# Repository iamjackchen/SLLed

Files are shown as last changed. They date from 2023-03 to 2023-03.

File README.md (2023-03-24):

# SLLed

A decorative lighting piece I designed and built for Valentine's day. The project is called "SLLed" because the intended recipient had supposedly caught me talking about singly-linked lists in my sleep.

Inspired by https://www.instructables.com/DIY-LED-heart/. 

</br>

## Hardware

I first started by building a schematic in KiCAD. Some design considerations:

 - I was at uni and didn't have access to my usual soldering equipment, so I had to get my PCB assembled by its manufacturer. This meant that my component selection was restricted to what the manufacturer had available. 

 - I also didn't have access to any mcu programming tools, so I wanted this module to be USB-programmable for ease of development. USB-C because, c'mon guys, it's 2023.

For the MCU I settled for the ATMega16U2, which is from the family of microcontrollers used in the classic Arduino line (the commonly-used 32U4 was out of stock). 

I added a 16MHZ crystal should I choose to implement some form of USB connectivity with a host device in the future (for which the 16U2's internal crystal would be insufficient).

I also designed a very simple MOSFET-based power-switching circuit so that this module can be powered both via battery and USB.
 
The final schematic may be found [here](https://github.com/iamjackchen/SLLed/blob/master/Hardware/schematic.pdf).

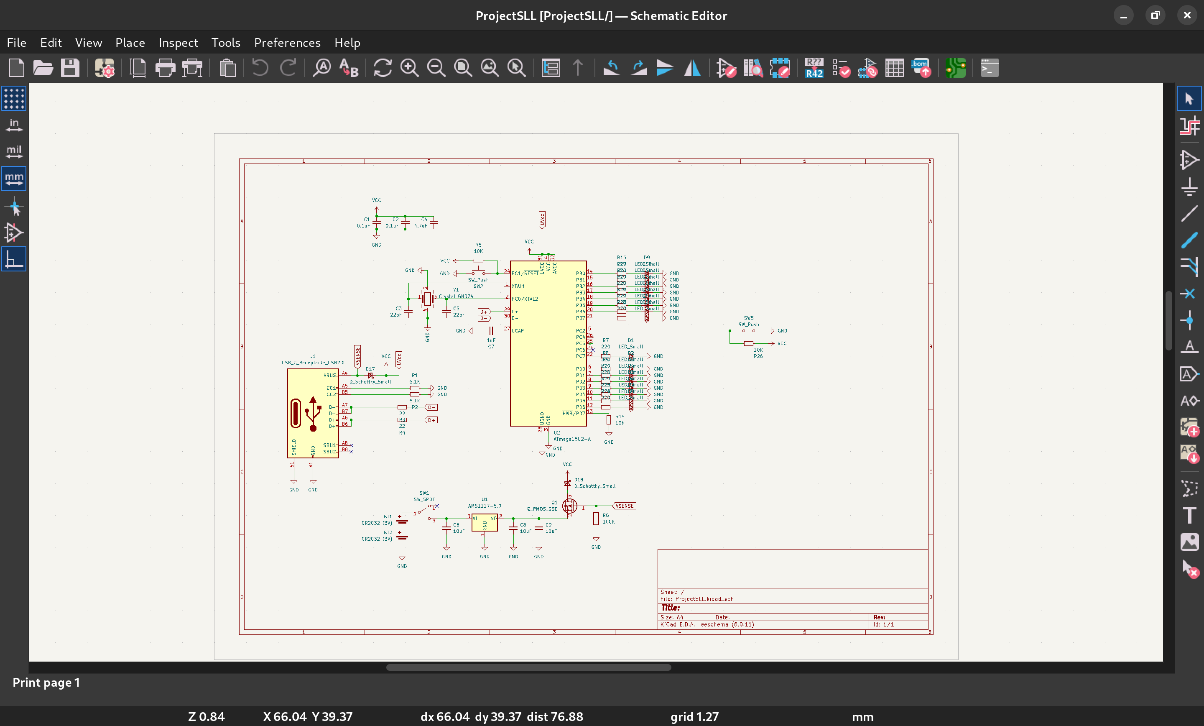
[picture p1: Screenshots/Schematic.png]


<br/>

I then assigned footprints to components and build a quick layout. Some design considerations:

 - For reasons of aesthetic purity, everything visible on the front-side of the PCB must be part of the heart. No vias outside of the heart!

 - Added a small hole to the top of the PCB, so you could thread a string through it and hang the module on somewhere

The geometry of the heart took some time to get right, but it turned out ok.

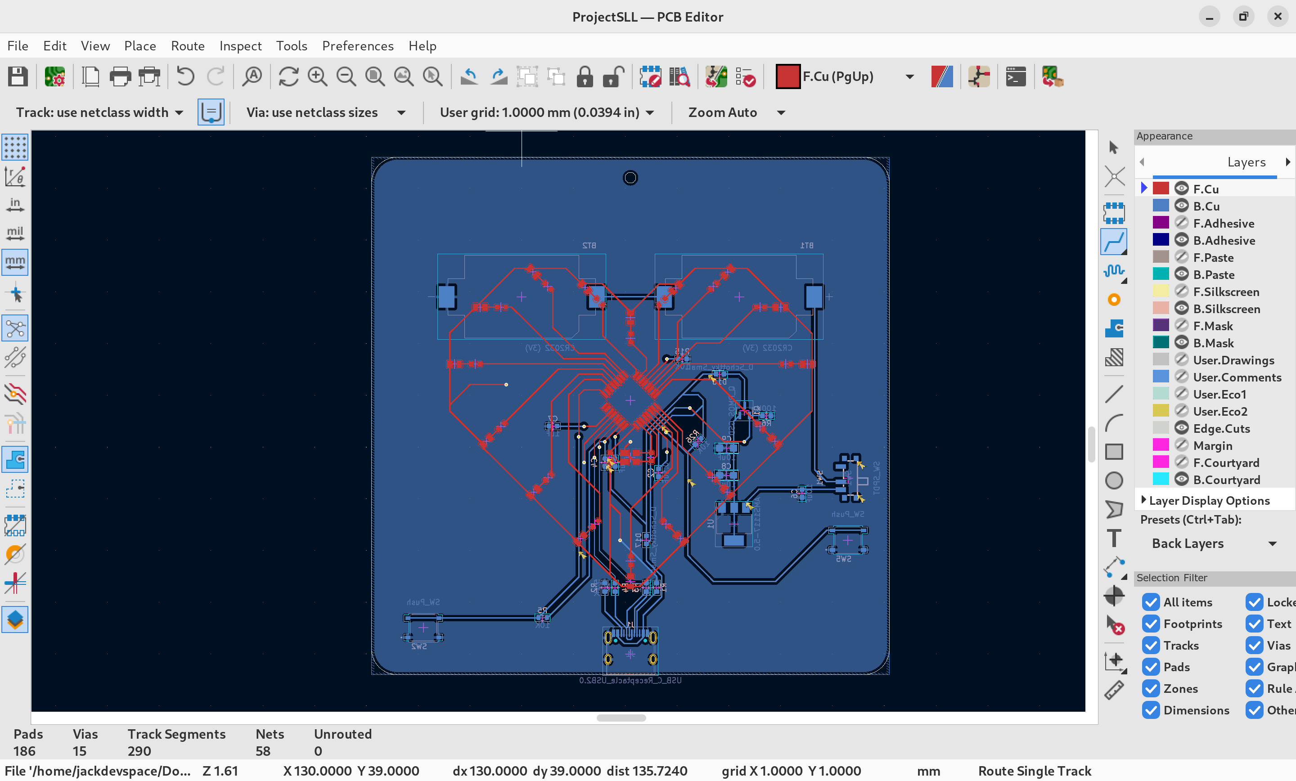
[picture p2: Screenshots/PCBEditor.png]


<br/>

I exported the Gerber files and BOM, and sent it off to JLCPCB for manufacture. Here are some renders: 

<p align="center">
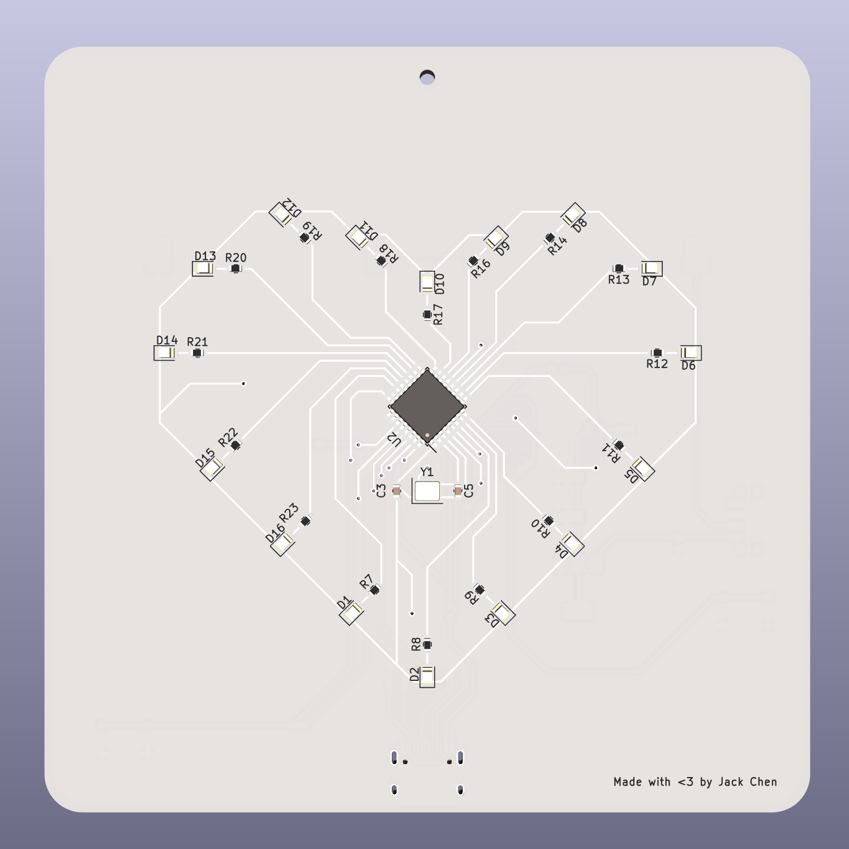
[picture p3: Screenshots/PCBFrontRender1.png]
  
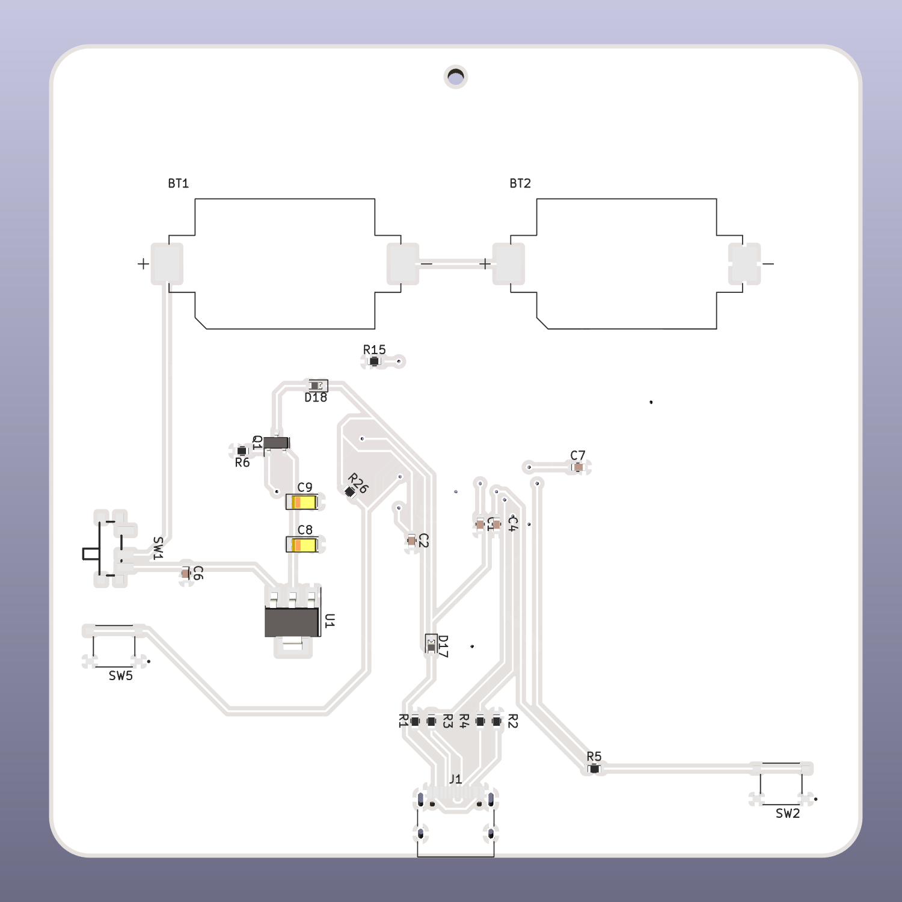
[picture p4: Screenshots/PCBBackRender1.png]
   
</p>

<br/>

## Software

In my humble opinion, using Arduino as a university student in _computer science_ is akin to intellectual cowardice. It is a sign that one lacks to bravery to face the almighty datasheet. /s

I programmed this in AVR C because I wanted to learn more about how microcontrollers worked at a lower level. Implementing I/O functions and interrupts by directly interacting with registers was a fun challenge and made the end result all the more rewarding. 

The [code](https://github.com/iamjackchen/SLLed/blob/master/Software/code.c) is structured as such:

 - I have system of decoding arrays so that the corresponding bits at the corresponding registers for each LED can be easily accessed via an index, where 0 is the top LED and the index moves through the heart clockwise.

 - The program runs on an infinite loop, which relies on a frame counter that increments and resets periodically. For each lighting mode, I have done some rudimentary maths to map the frame counter to the indices of the LEDs that need to be turned on or off.

 - An interrupt service routine is defined such that whenever the push-button (connected to Pin C2) is pressed, the loop resets and and the lighting mode changes.

There are currently 5 lighting modes built into the program : twinkle, heartbeat, vertical sweep, snake, and solid (hopefully these names are all self-explanatory).

<br/>

## Gallery

<p align="center">
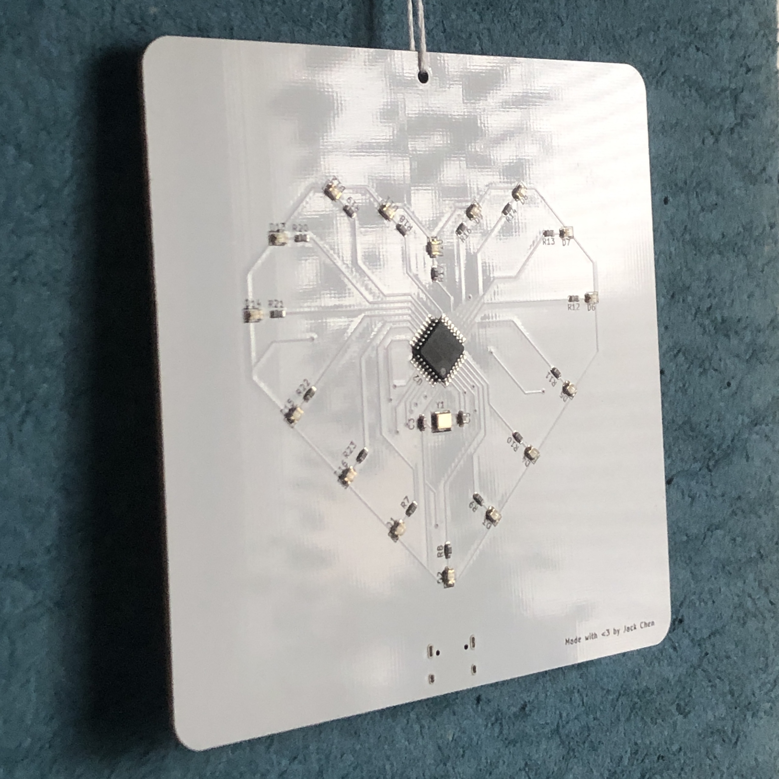
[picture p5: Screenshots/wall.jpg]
 
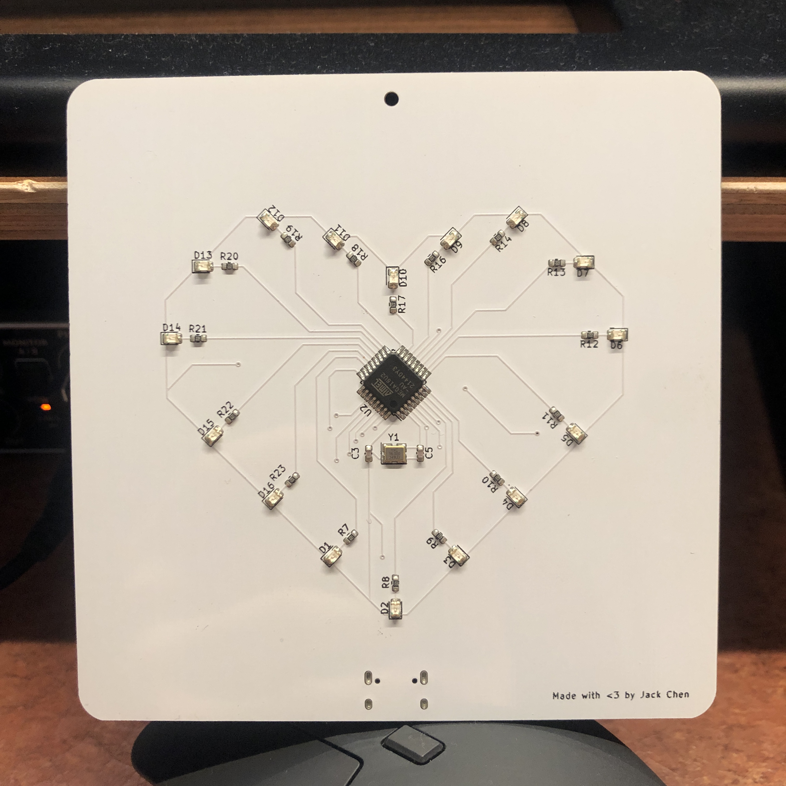
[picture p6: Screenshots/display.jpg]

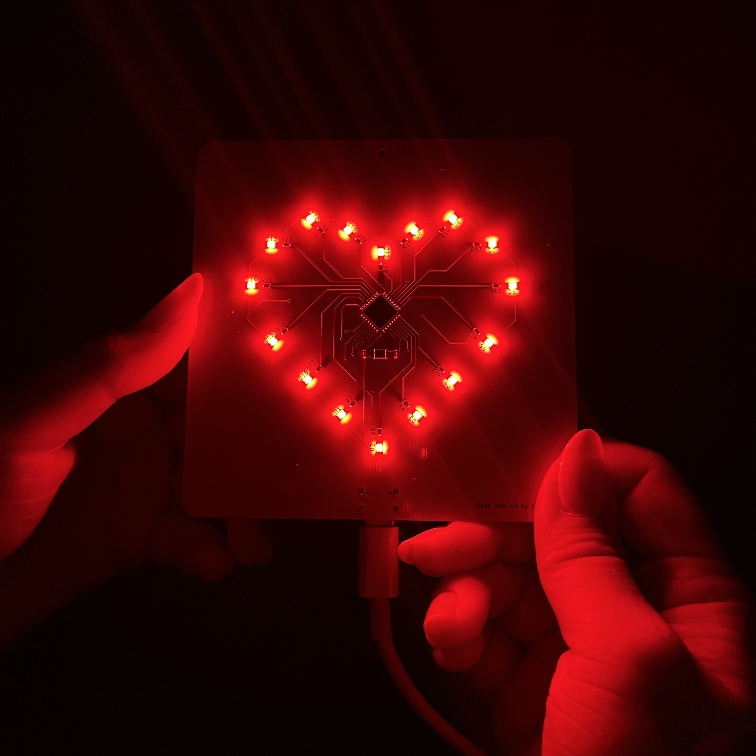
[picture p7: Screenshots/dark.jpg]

</p>

<p align="center">
 

</p>

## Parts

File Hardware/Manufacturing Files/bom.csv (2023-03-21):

Designator | Footprint | Quantity | Value | LCSC Part #
BT1, BT2 | BAT_CR2032-BS-6-1 | 2 | CR2032 (3V) | C70377
C1 | 0603 | 1 | 0.1uF | C15849
C2 | 0603 | 1 | 0.1uF | C15849
C3 | 0603 | 1 | 22pF | C1653
C4 | 0603 | 1 | 4.7uF | C19666
C5 | 0603 | 1 | 22pF | C1653
C6 | 0603 | 1 | 10uF | C19702
C7 | 0603 | 1 | 1uF | C15849
C8, C9 | CP_EIA-3216-18_Kemet-A | 2 | 10uF | C7171
D1 | 0805 | 1 | LED_Small | C84256
D10 | 0805 | 1 | LED_Small | C84256
D11 | 0805 | 1 | LED_Small | C84256
D12 | 0805 | 1 | LED_Small | C84256
D13 | 0805 | 1 | LED_Small | C84256
D14 | 0805 | 1 | LED_Small | C84256
D15 | 0805 | 1 | LED_Small | C84256
D16 | 0805 | 1 | LED_Small | C84256
D2 | 0805 | 1 | LED_Small | C84256
D3 | 0805 | 1 | LED_Small | C84256
D4 | 0805 | 1 | LED_Small | C84256
D5 | 0805 | 1 | LED_Small | C84256
D6 | 0805 | 1 | LED_Small | C84256
D7 | 0805 | 1 | LED_Small | C84256
D8 | 0805 | 1 | LED_Small | C84256
D9 | 0805 | 1 | LED_Small | C84256
J1 | USB_C_Receptacle_HRO_TYPE-C-31-M-12 | 1 | USB_C_Receptacle_USB2.0 | C165948
Q1 | SOT-23 | 1 | Q_PMOS_GSD | C15127
R1 | 0603 | 1 | 5.1K | C23186
R10 | 0603 | 1 | 220 | C22962
R11 | 0603 | 1 | 220 | C22962
R12 | 0603 | 1 | 220 | C22962
R13 | 0603 | 1 | 220 | C22962
R14 | 0603 | 1 | 220 | C22962
R15 | 0603 | 1 | 10K | C25804
R16 | 0603 | 1 | 220 | C22962
R17 | 0603 | 1 | 220 | C22962
R18 | 0603 | 1 | 220 | C22962
R19 | 0603 | 1 | 220 | C22962
R2 | 0603 | 1 | 5.1K | C23186
R20 | 0603 | 1 | 220 | C22962
R21 | 0603 | 1 | 220 | C22962
R22 | 0603 | 1 | 220 | C22962
R23 | 0603 | 1 | 220 | C22962
R26 | 0603 | 1 | 10K | C25804
R3 | 0603 | 1 | 22 | C23345
R4 | 0603 | 1 | 22 | C23345
R5 | 0603 | 1 | 10K | C25804
R6 | 0603 | 1 | 100K | C25803
R7 | 0603 | 1 | 220 | C22962
R8 | 0603 | 1 | 220 | C22962
R9 | 0603 | 1 | 220 | C22962
SW1 | SW-SMD_MK-12C02-G020 | 1 | SW_SPDT | C963206
SW2, SW5 | SW_TS-1187A-B-A-B | 2 | SW_Push | C318884
U1 | SOT-223-3_TabPin2 | 1 | AMS1117-5.0 | C6187
U2 | TQFP-32_7x7mm_P0.8mm | 1 | ATmega16U2-A | C59019
Y1 | Crystal_SMD_3225-4Pin_3.2x2.5mm | 1 | Crystal_GND24 | C13738

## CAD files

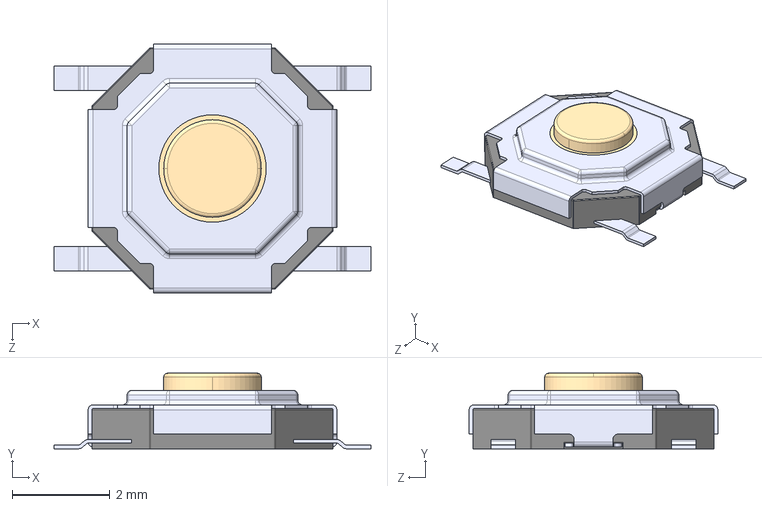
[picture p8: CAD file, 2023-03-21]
Hardware/Footprints/TS-1187A-B-A-B.step
6.50 x 1.55 x 5.10 mm

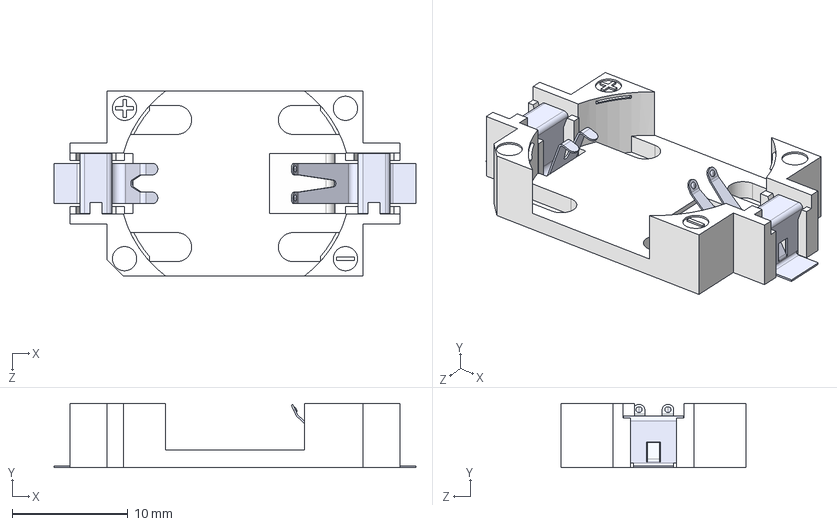
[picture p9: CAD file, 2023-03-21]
Hardware/Footprints/CR2032-BS-6-1.step
31.3 x 5.55 x 16.0 mm

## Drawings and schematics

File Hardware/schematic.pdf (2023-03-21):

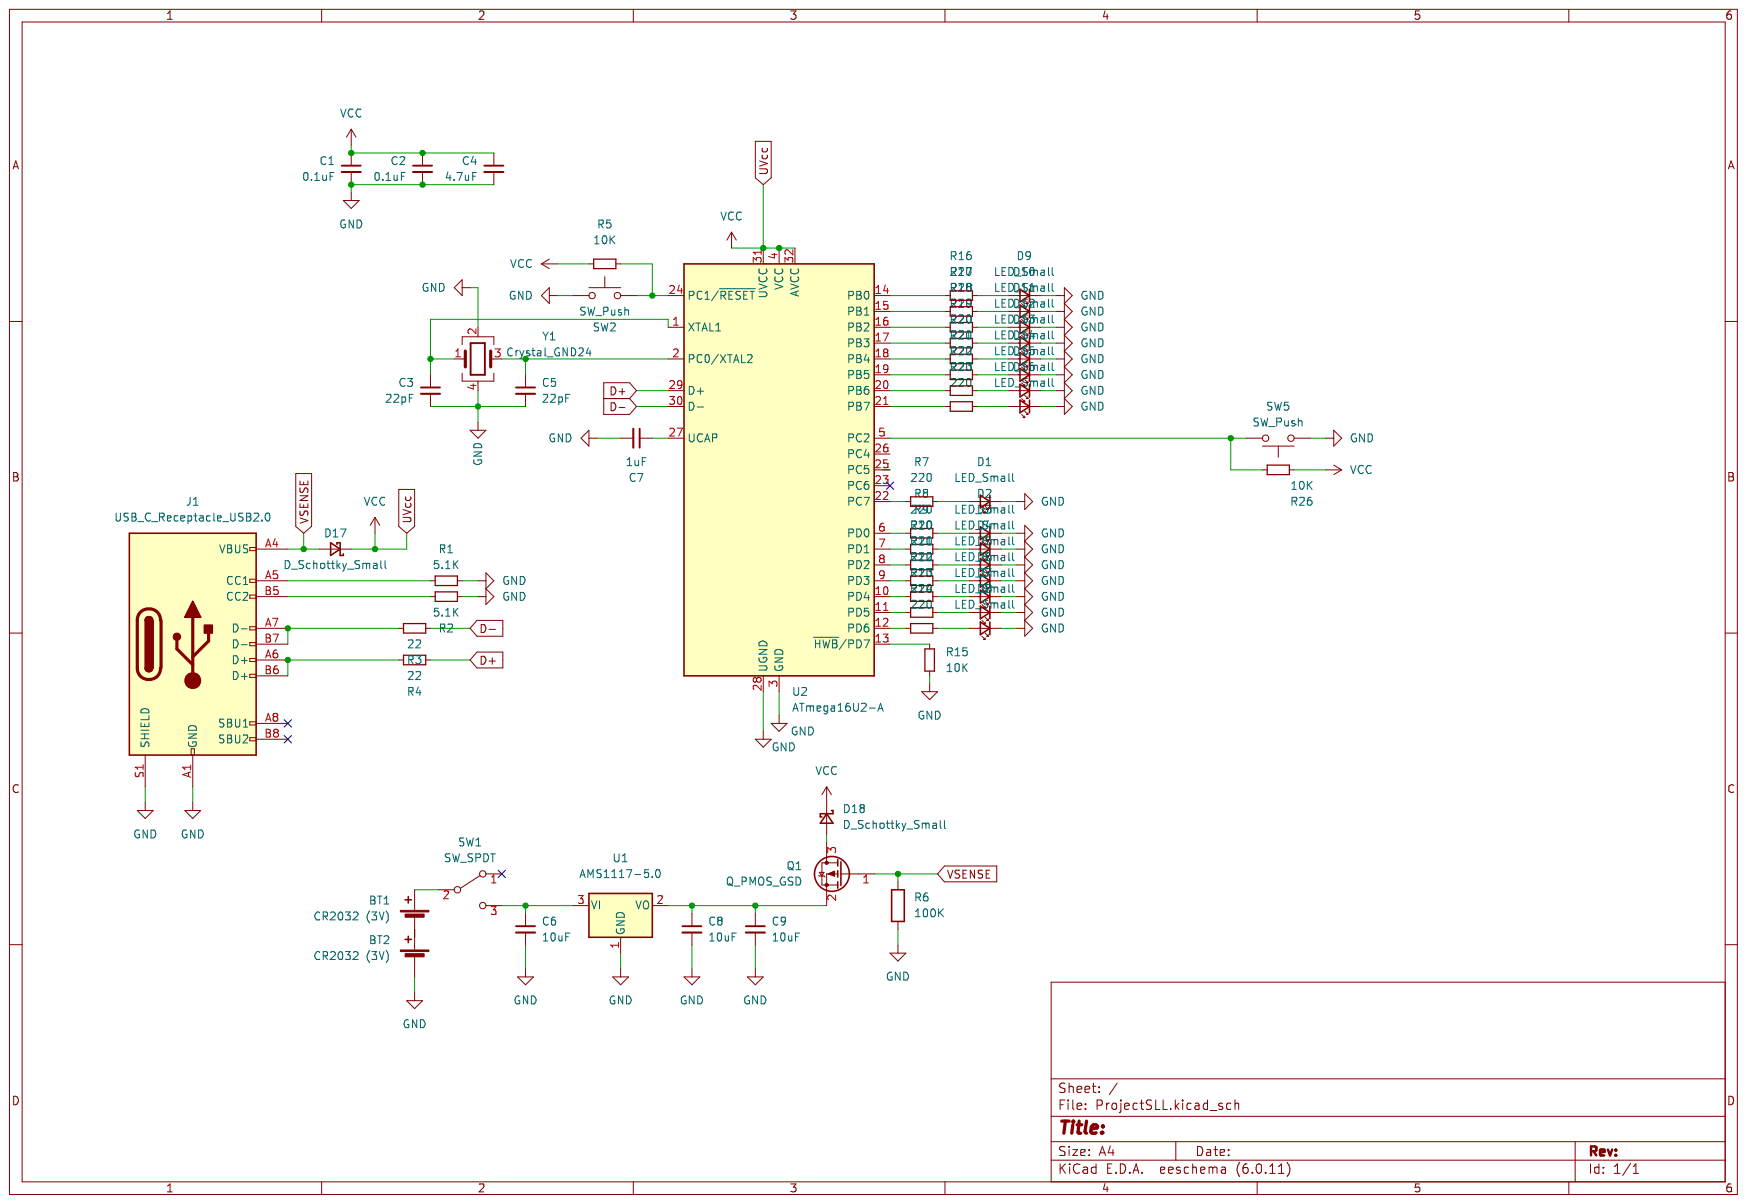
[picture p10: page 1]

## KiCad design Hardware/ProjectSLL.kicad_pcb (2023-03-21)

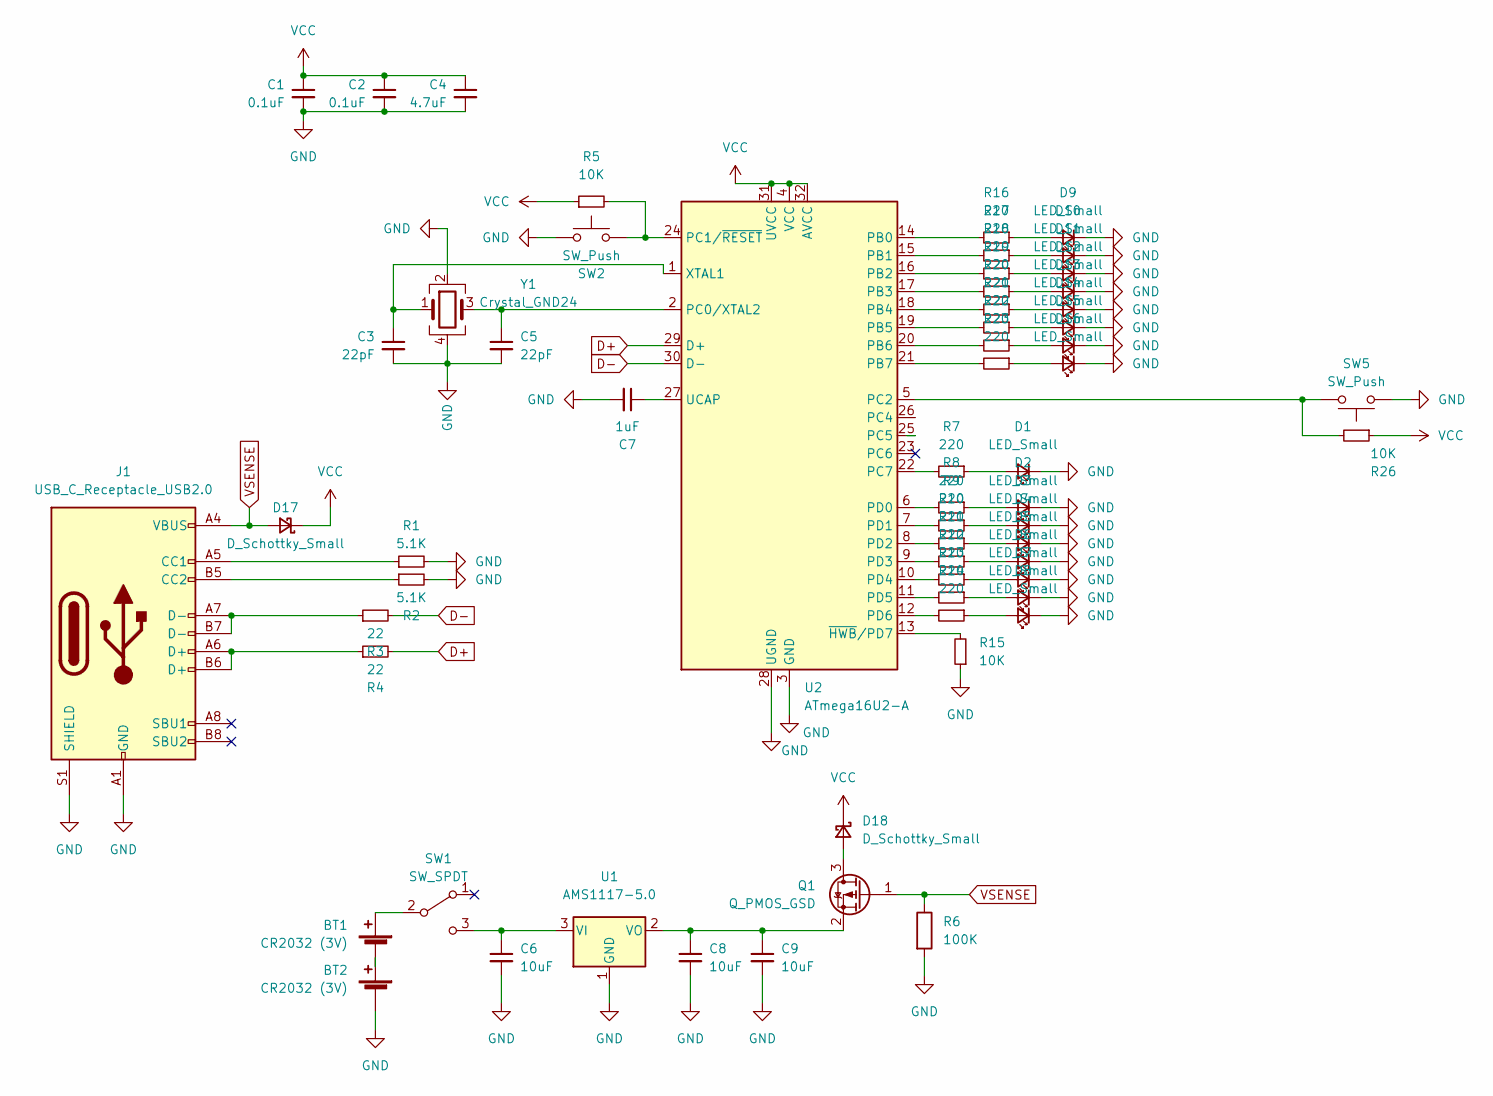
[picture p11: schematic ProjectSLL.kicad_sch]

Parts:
BT1, BT2: CR2032 (3V); BAT_CR2032-BS-6-1; LCSC C70377
C1, C2: 0.1uF; C_0603_1608Metric
C3, C5: 22pF; C_0603_1608Metric
C4: 4.7uF; C_0603_1608Metric
C6: 10uF; C_0603_1608Metric
C7: 1uF; C_0603_1608Metric
C8, C9: 10uF; CP_EIA-3216-18_Kemet-A; LCSC C7171
D1, D2, D3, D4, D5, D6, D7, D8, D9, D10, D11, D12, D13, D14, D15, D16: LED_Small; LED_0805_2012Metric
D17, D18: D_Schottky_Small; D_0603_1608Metric
J1: USB_C_Receptacle_USB2.0; USB_C_Receptacle_HRO_TYPE-C-31-M-12; LCSC C165948
Q1: Q_PMOS_GSD; SOT-23; LCSC C15127
R1, R2: 5.1K; R_0603_1608Metric
R3, R4: 22; R_0603_1608Metric
R5, R15, R26: 10K; R_0603_1608Metric
R6: 100K; R_0603_1608Metric
R7, R8, R9, R10, R11, R12, R13, R14, R16, R17, R18, R19, R20, R21, R22, R23: 220; R_0603_1608Metric
SW1: SW_SPDT; SW-SMD_MK-12C02-G020; LCSC C963206
SW2, SW5: SW_Push; SW_TS-1187A-B-A-B; LCSC C318884
U1: AMS1117-5.0; SOT-223-3_TabPin2; LCSC C6187
U2: ATmega16U2-A; TQFP-32_7x7mm_P0.8mm; LCSC C59019
Y1: Crystal_GND24; Crystal_SMD_3225-4Pin_3.2x2.5mm; LCSC C13738

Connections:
D+: R4.2, U2.29 (D+)
D-: R3.2, U2.30 (D-)
GND: BT2.2 (-), C1.2, C2.2, C3.2, C4.2, C5.2, C6.2, C7.2, C8.2, C9.2, D1.1 (K), D2.1 (K), D3.1 (K), D4.1 (K), D5.1 (K), D6.1 (K), D7.1 (K), D8.1 (K), D9.1 (K), D10.1 (K), D11.1 (K), D12.1 (K), D13.1 (K), D14.1 (K), D15.1 (K), D16.1 (K), J1.A1 (GND), J1.A12 (GND), J1.B1 (GND), J1.B12 (GND), J1.S1 (SHIELD), R1.2, R2.2, R6.2, R15.1, SW2.1, SW5.1, U1.1 (GND), U2.3 (GND), U2.28 (UGND), Y1.2, Y1.4
unnamed: BT1.1 (+), SW1.2 (B)
unnamed: BT1.2 (-), BT2.1 (+)
unnamed: C3.1, U2.1 (XTAL1), Y1.1
unnamed: C5.1, U2.2 (PC0/XTAL2), Y1.3
unnamed: C6.1, SW1.3 (C), U1.3 (VI)
unnamed: C7.1, U2.27 (UCAP)
unnamed: C8.1, C9.1, Q1.2 (S), U1.2 (VO)
unnamed: D1.2 (A), R7.1
unnamed: D2.2 (A), R8.1
unnamed: D3.2 (A), R9.1
unnamed: D4.2 (A), R10.1
unnamed: D5.2 (A), R11.1
unnamed: D6.2 (A), R12.1
unnamed: D7.2 (A), R13.1
unnamed: D8.2 (A), R14.1
unnamed: D9.2 (A), R16.1
unnamed: D10.2 (A), R17.1
unnamed: D11.2 (A), R18.1
unnamed: D12.2 (A), R19.1
unnamed: D13.2 (A), R20.1
unnamed: D14.2 (A), R21.1
unnamed: D15.2 (A), R22.1
unnamed: D16.2 (A), R23.1
unnamed: D18.2 (A), Q1.3 (D)
unnamed: J1.A5 (CC1), R1.1
unnamed: J1.A6 (D+), J1.B6 (D+), R4.1
unnamed: J1.A7 (D-), J1.B7 (D-), R3.1
unnamed: J1.B5 (CC2), R2.1
unnamed: R5.2, SW2.2, U2.24 (PC1/~RESET)
unnamed: R7.2, U2.22 (PC7)
unnamed: R8.2, U2.6 (PD0)
unnamed: R9.2, U2.7 (PD1)
unnamed: R10.2, U2.8 (PD2)
unnamed: R11.2, U2.9 (PD3)
unnamed: R12.2, U2.10 (PD4)
unnamed: R13.2, U2.11 (PD5)
unnamed: R14.2, U2.12 (PD6)
unnamed: R15.2, U2.13 (~HWB/PD7)
unnamed: R16.2, U2.14 (PB0)
unnamed: R17.2, U2.15 (PB1)
unnamed: R18.2, U2.16 (PB2)
unnamed: R19.2, U2.17 (PB3)
unnamed: R20.2, U2.18 (PB4)
unnamed: R21.2, U2.19 (PB5)
unnamed: R22.2, U2.20 (PB6)
unnamed: R23.2, U2.21 (PB7)
unnamed: R26.2, SW5.2, U2.5 (PC2)
VCC: C1.1, C2.1, C4.1, D17.1 (K), D18.1 (K), R5.1, R26.1, U2.4 (VCC), U2.31 (UVCC), U2.32 (AVCC)
VSENSE: D17.2 (A), J1.A4 (VBUS), J1.A9 (VBUS), J1.B4 (VBUS), J1.B9 (VBUS), Q1.1 (G), R6.1

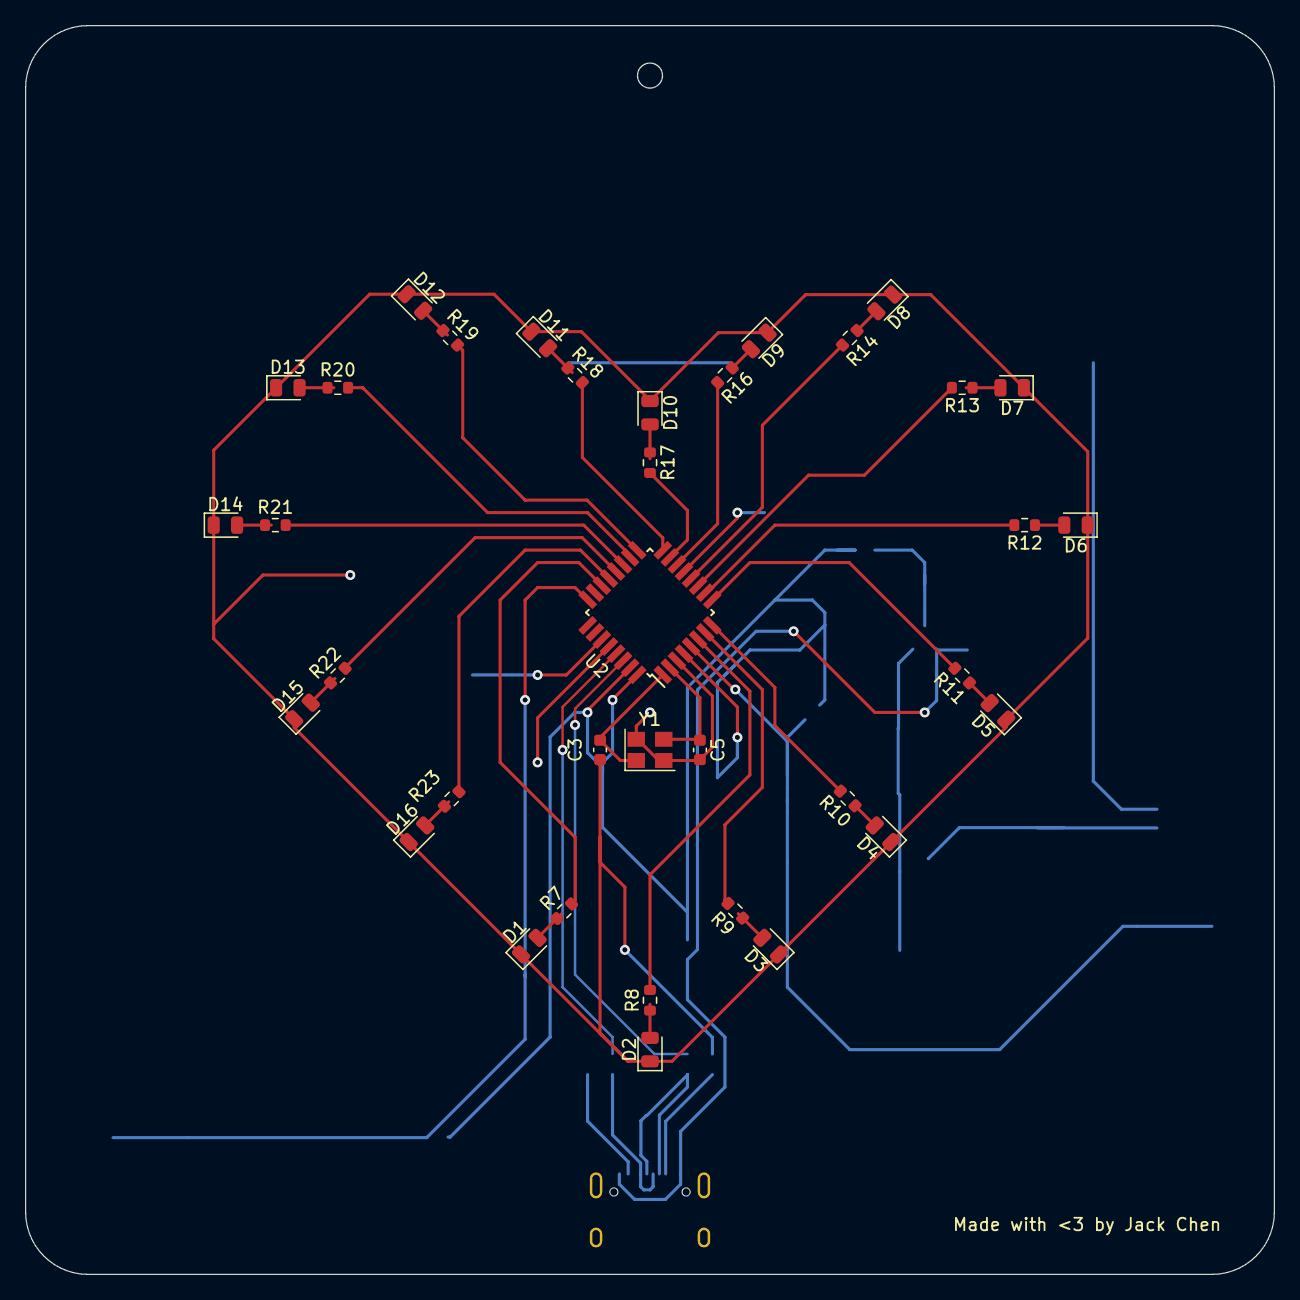
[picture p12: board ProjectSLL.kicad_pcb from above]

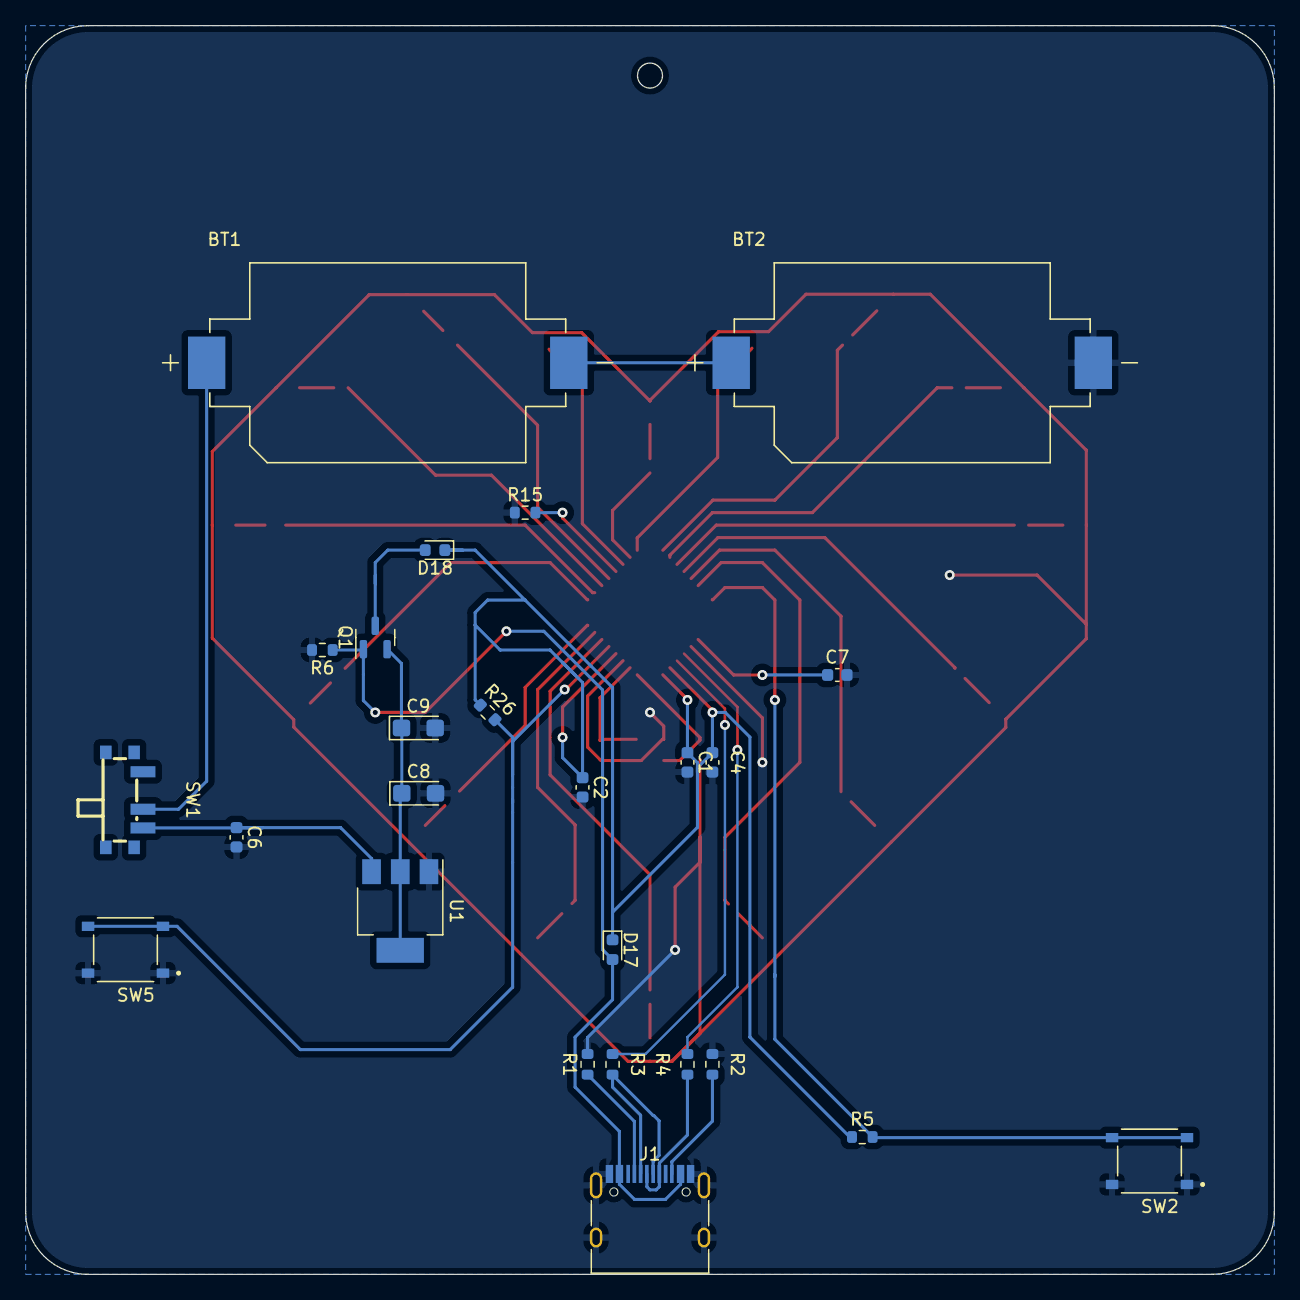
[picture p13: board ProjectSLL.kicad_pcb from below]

Board: 2 copper layers, 100.0 x 100.0 mm, 61 parts (25 on the bottom side), 52 nets.

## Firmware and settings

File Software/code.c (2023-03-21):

#define __AVR_ATmega16U2__

#include <avr/io.h> 
#include <avr/interrupt.h> 
#include <util/delay.h>

uint8_t counter = 0;
uint8_t mode = 0;

const uint8_t NUM_MODES = 5;


volatile uint8_t* ledmr[3] = {&DDRB, &DDRC, &DDRD};
volatile uint8_t* ledr[3] = {&PORTB, &PORTC, &PORTD};
const uint8_t conv[16] = {0, 0, 2, 2, 2, 2, 2, 2, 2, 1, 0, 0, 0, 0, 0, 0};

const uint8_t ledn[16] = {PB1, PB0, PD6, PD5, PD4, PD3, PD2, PD1, PD0, PC7, PB7, PB6, PB5, PB4, PB3, PB2};

void ledON(uint8_t index) { *(ledr[conv[index]]) |= (1 << ledn[index]); }
void ledOFF(uint8_t index) { *(ledr[conv[index]]) &= ~(1 << ledn[index]); }

void init_leds() {
    for (uint8_t i = 0; i < 16; i++) {
        *(ledmr[conv[i]]) |= (1 << ledn[i]);
        *(ledr[conv[i]]) &= ~(1 << ledn[i]);
    }
}

void allON() {
    for (uint8_t i = 0; i < 16; i++) {
        *(ledr[conv[i]]) |= (1 << ledn[i]);
    }
}

void allOFF() {
    for (uint8_t i = 0; i < 16; i++) {
        *(ledr[conv[i]]) &= ~(1 << ledn[i]);
    }
}


void init_interrupts()
{
    // Configure Pin C2 as input
    DDRC &= ~(1 << PC2);
    // Enable pull-up resistor on Pin C2
    PORTC |= (1 << PC2);

    // Enable interrupt on Pin C2 (PCINT11)
    PCICR |= (1 << PCIE1) | (1 << PCIE0); 
    PCMSK1 |= (1 << PCINT11); 
}

ISR(PCINT1_vect) {

    if (PINC & (1 << PC2)) {
        allOFF();

        mode = (mode+1) % NUM_MODES;
        counter = 0;

        if (mode == NUM_MODES - 1) {
            allON();
        }
    }

}

void startup() {

    // . .
    // . - . .  - - -    . . . -    . 
    // - . - -  - - -   . . -
    _delay_ms(100);

    allON();
    _delay_ms(25);
    allOFF();
    _delay_ms(25);
    allON();
    _delay_ms(25);
    allOFF();
    _delay_ms(25);

    _delay_ms(150);

    allON();
    _delay_ms(25);
    allOFF();
    _delay_ms(25);
    allON();
    _delay_ms(50);
    allOFF();
    _delay_ms(25);
    allON();
    _delay_ms(25);
    allOFF();
    _delay_ms(25);
    allON();
    _delay_ms(25);
    allOFF();
    _delay_ms(25);

    _delay_ms(75);

    allON();
    _delay_ms(50);
    allOFF();
    _delay_ms(25);
    allON();
    _delay_ms(50);
    allOFF();
    _delay_ms(25);
    allON();
    _delay_ms(50);
    allOFF();
    _delay_ms(25);

    _delay_ms(75);

    allON();
    _delay_ms(25);
    allOFF();
    _delay_ms(25);
    allON();
    _delay_ms(25);
    allOFF();
    _delay_ms(25);
    allON();
    _delay_ms(25);
    allOFF();
    _delay_ms(25);
    allON();
    _delay_ms(50);
    allOFF();
    _delay_ms(25);

    _delay_ms(75);

    allON();
    _delay_ms(25);
    allOFF();
    _delay_ms(25);

    _delay_ms(150);

    allON();
    _delay_ms(50);
    allOFF();
    _delay_ms(25);
    allON();
    _delay_ms(25);
    allOFF();
    _delay_ms(25);
    allON();
    _delay_ms(50);
    allOFF();
    _delay_ms(25);
    allON();
    _delay_ms(50);
    allOFF();
    _delay_ms(25);

    _delay_ms(75);

    allON();
    _delay_ms(50);
    allOFF();
    _delay_ms(25);
    allON();
    _delay_ms(50);
    allOFF();
    _delay_ms(25);
    allON();
    _delay_ms(50);
    allOFF();
    _delay_ms(25);

    _delay_ms(75);

    allON();
    _delay_ms(25);
    allOFF();
    _delay_ms(25);
    allON();
    _delay_ms(25);
    allOFF();
    _delay_ms(25);
    allON();
    _delay_ms(50);
    allOFF();
    _delay_ms(25);

    _delay_ms(75);


}

int main()
{

    init_leds();
    init_interrupts();

    startup();

    sei(); //Enable global interrupts


    while (1) {

        if (mode == 0) {
            counter = counter%8;
            if (counter%4 == 0) { //twinkle1
                for (uint8_t i = 0; i < 16; i+=2) {
                    ledON(i);
                }

                for (uint8_t i = 1; i < 16; i+=2) {
                    ledOFF(i);
                }

            } else if (counter%2 == 0) { //twinkle2-- "else if" very important so that twinkle2 is not triggered after twinkle1
                for (uint8_t i = 0; i < 16; i+=2) {
                    ledOFF(i);
                }

                for (uint8_t i = 1; i < 16; i+=2) {
                    ledON(i);
                }
            }

        } else if (mode == 1) {
            counter = counter%10;
            if (counter == 0 || counter == 2) {
                allON();
            } else if (counter == 1 || counter == 3) {
                allOFF();
            }

        } else if (mode == 2) {
            counter = counter%18;
            if (counter < 9) {
                if(counter != 8)
                    ledON(8+counter);
                ledON(8-counter);
            } else {
                if(counter != 17)
                    ledOFF(8+(counter-9));
                ledOFF(8-(counter-9));
            }
            
        } else if (mode == 3) {
            counter = counter%32;
            if (counter < 16)
                ledON(counter);
            else
                ledOFF(counter-16);
            
        } else if (mode == 4) {
            //do nothing
        }


        counter++;
        _delay_ms(25);

    }

    return 0;
}



/* LED Mappings (Clockwise, starting from top)
17  B1
16  B0
14  D6
13  D5
12  D4
11  D3
10  D2
09  D1
08  D0
07  C7
23  B7
22  B6
21  B5
20  B4
19  B3
18  B2
*/

/* MODES
0 - twinkle
1 - heart beat
2 - vertical snake
3 - snake
4 - solid

*/
